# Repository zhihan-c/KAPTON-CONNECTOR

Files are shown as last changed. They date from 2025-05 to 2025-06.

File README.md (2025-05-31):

## Kapton Heater System for Oxidizer Tank Pressure Regulation

This system uses a 24V, 14.6A Kapton trace heater to regulate the pressure inside a nitrous oxide oxidizer tank, particularly in colder environments where vapor pressure drops below optimal levels. The heater is PWM-controlled via a high-current N-channel MOSFET, allowing for precise thermal regulation.

Designed by Brandon Moncriefe and Aslan Lauzon for QRET

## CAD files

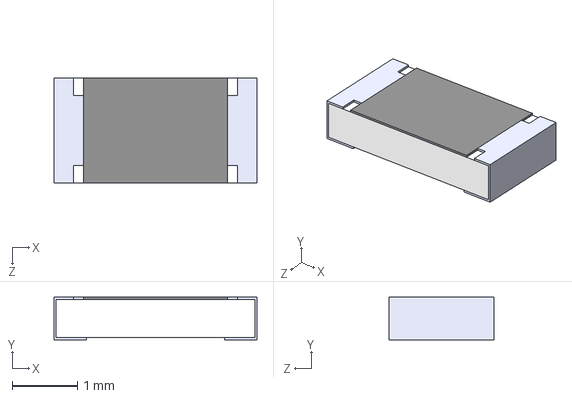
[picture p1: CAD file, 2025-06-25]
Component Footprints/CRCW120627R0FKEAHP/CRCW120627R0FKEAHP.step
3.10 x 0.65 x 1.60 mm

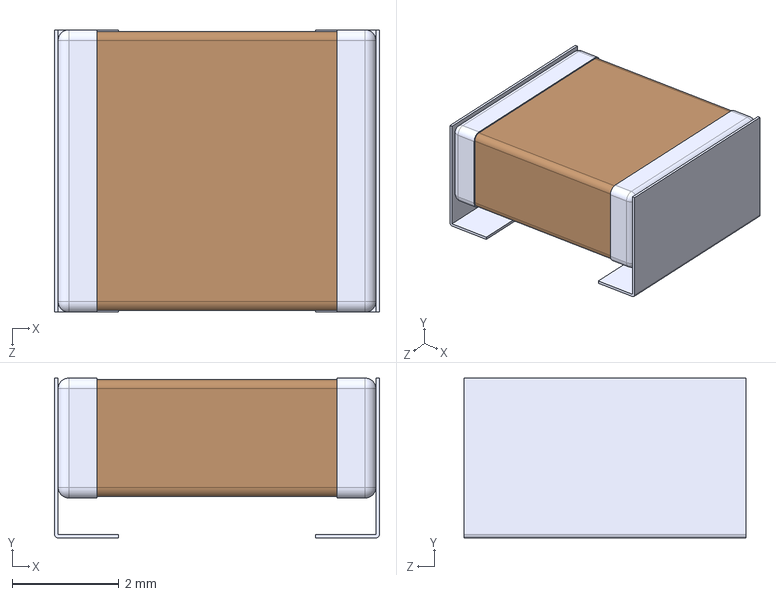
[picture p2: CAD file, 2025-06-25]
Component Footprints/KCM55LR71J475KH01K/KCM55LR71J475KH01K.step
6.10 x 3.00 x 5.30 mm

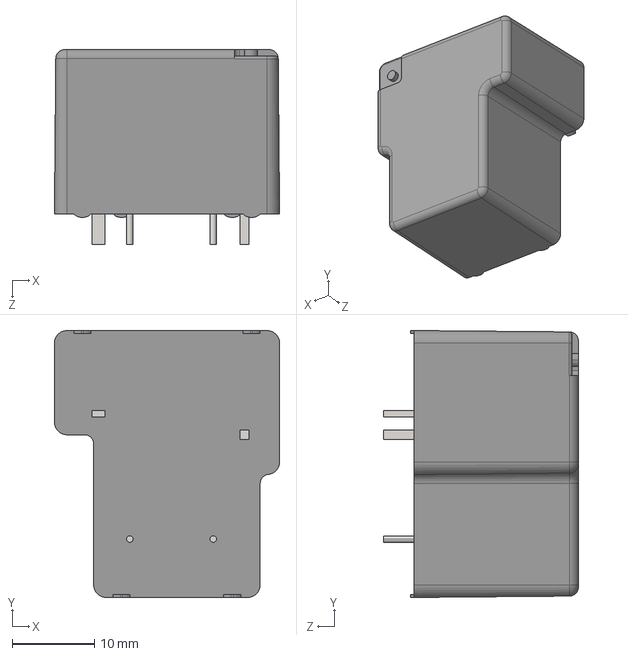
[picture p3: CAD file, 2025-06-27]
Component Footprints/LIB_T9AS1D12-5/T9AS1D12-5/3D/T9AS1D12-5.stp
27.4 x 32.5 x 23.7 mm

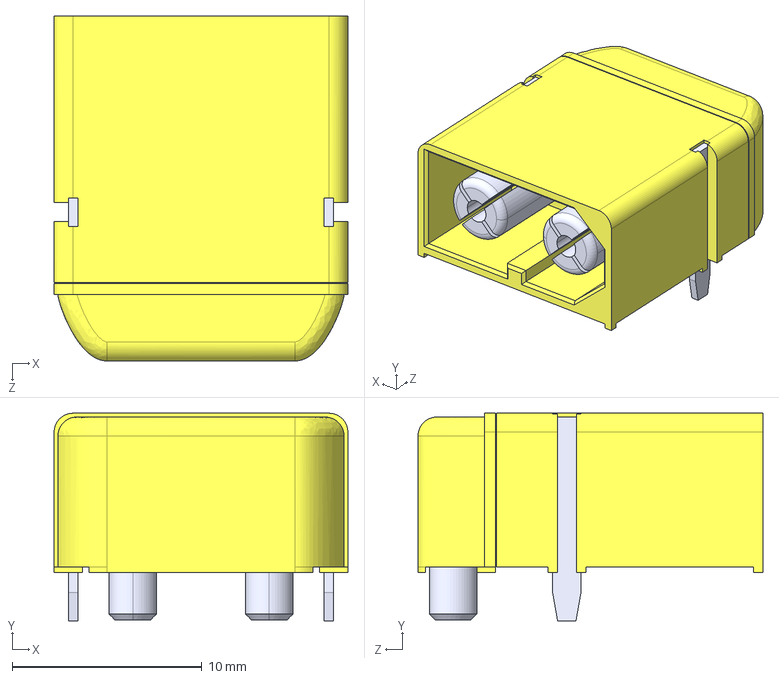
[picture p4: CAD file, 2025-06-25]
Component Footprints/XT60PW-M/XT60PW-M.step
15.5 x 11.0 x 18.2 mm

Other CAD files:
Component Footprints/LIB_T9AS1D12-5/T9AS1D12-5/Allegro/t9as1d125.psm
Component Footprints/LIB_T9AS1D12-5/T9AS1D12-5/DEHDL/t9as1d12_5/chips/chips.prt
Component Footprints/LIB_V20DM100C-M3_I/V20DM100C-M3_I/Allegro/v40dl45bpm3i.psm
Component Footprints/LIB_V20DM100C-M3_I/V20DM100C-M3_I/DEHDL/v20dm100c_m3_i/chips/chips.prt

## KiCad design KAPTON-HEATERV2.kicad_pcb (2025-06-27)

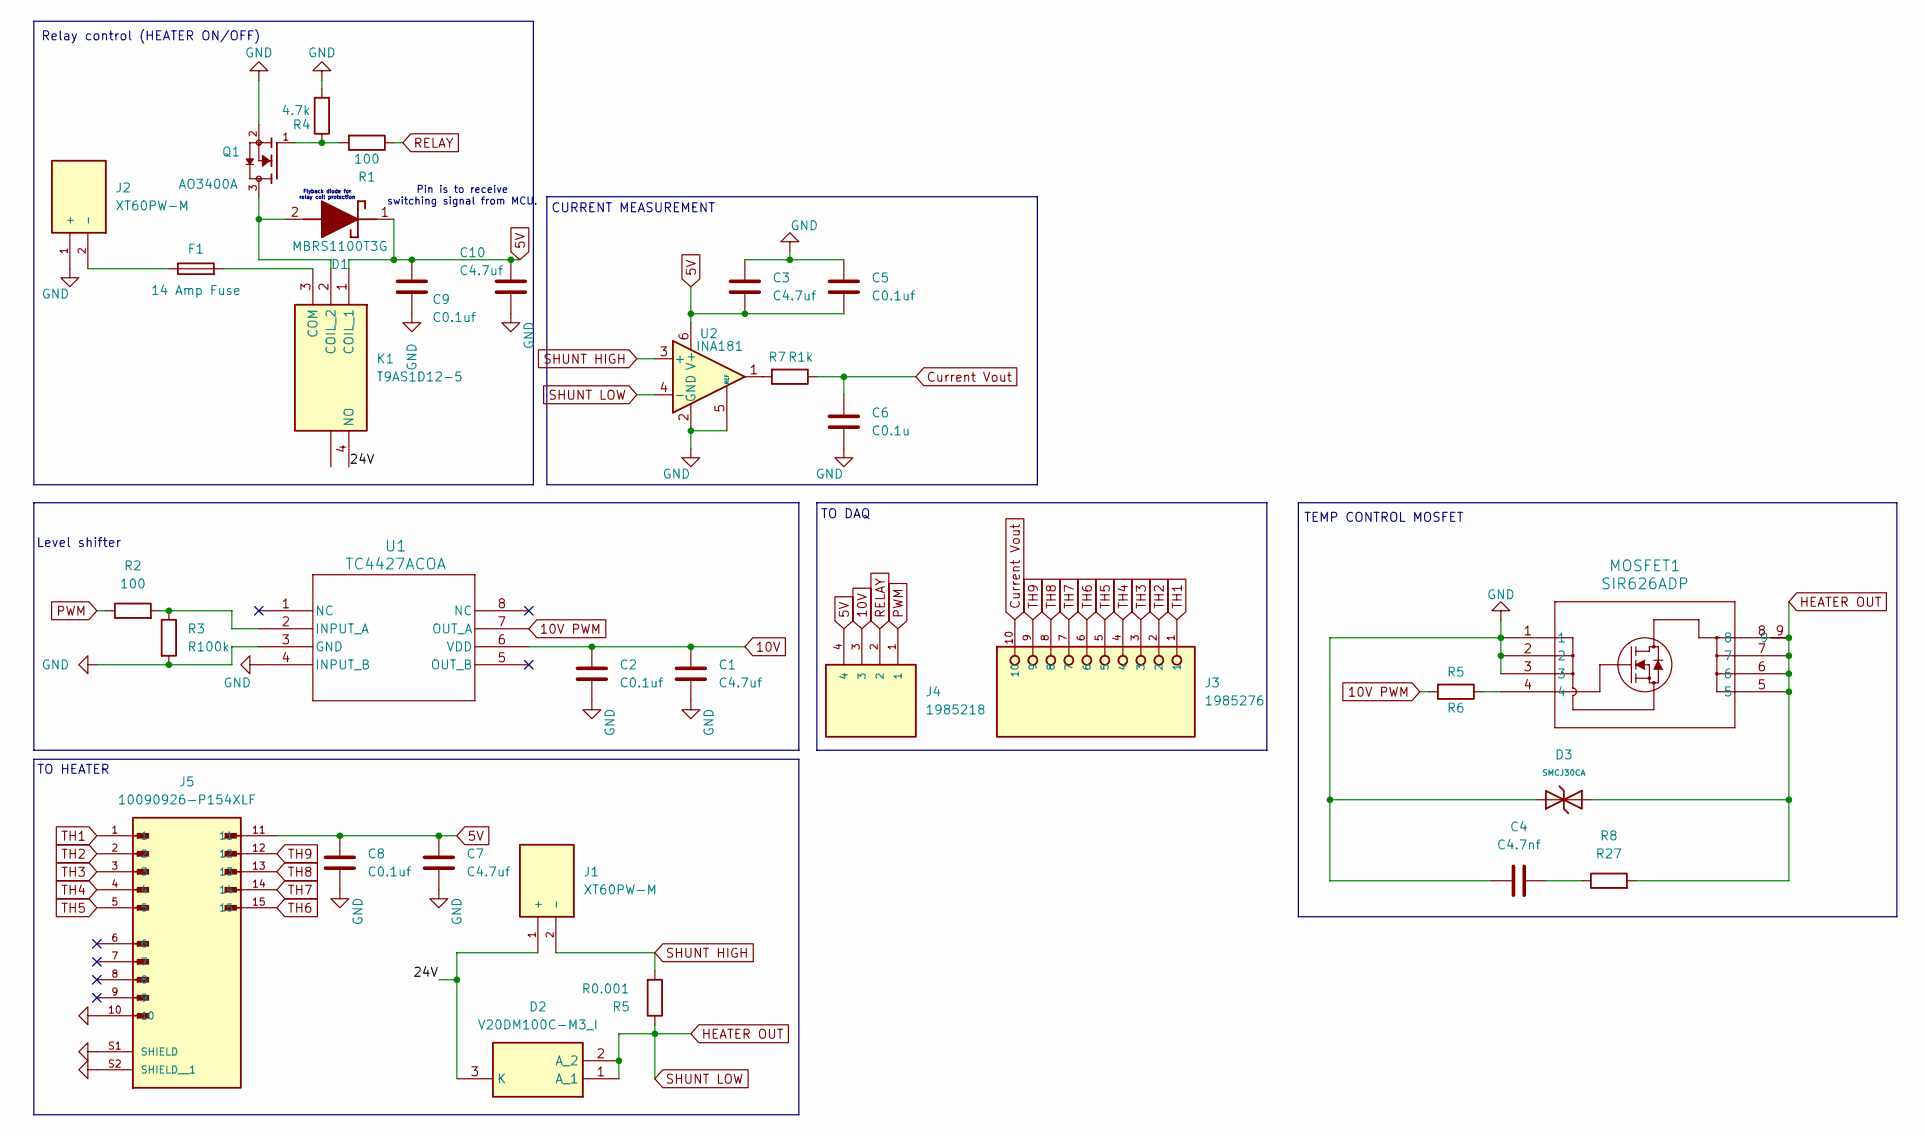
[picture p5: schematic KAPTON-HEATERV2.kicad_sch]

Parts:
C1, C3, C7, C10: C4.7uf; C_0805_2012Metric
C2, C5, C8, C9: C0.1uf; C_0805_2012Metric
C4: C4.7nf; CAPC6153X300N
C6: C0.1u; C_0805_2012Metric
D1: MBRS1100T3G; DIOM5436X247N; Mouser Part Number 863-MBRS1100T3G
D2: V20DM100C-M3_I; V40DL45BPM3I; Mouser Part Number 78-V20DM100C-M3/I
D3: SMCJ30CA; D_SMC; Part SMCJ30CA; LCSC C19077607
F1: 14 Amp Fuse; FUSRR508W60L835T400H810
J1, J2: XT60PW-M; AMASS_XT60PW-M; PARTREV V1.2
J3: 1985276; PHOENIX_1985276
J4: 1985218; TE_1985218; PARTREV 29.03.2021
J5: 10090926-P154XLF; AMPHENOL_10090926-P154XLF; PARTREV H
K1: T9AS1D12-5; T9AS1D125; Manufacturer_Part_Number T9AS1D12-5; Mouser Part Number 655-T9AS1D12-5
MOSFET1: SIR626ADP; POWERPAK_SO-8_SINGLE_VIS
Q1: AO3400A; SOT95P280X125-3N; PARTREV L
R1, R2: 100; R_0805_2012Metric
R3: R100k; R_0805_2012Metric
R4: 4.7k; R_0805_2012Metric
R5: R0.001; RESC6432X90N
R6: R5; R_0805_2012Metric
R7: R1k; R_0805_2012Metric
R8: R27; R_1206_3216Metric
U1: TC4427ACOA; SOIC8-N_MC_MCH
U2: INA181; SOT-23-6

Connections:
5V: C3.2, C5.2, C7.1, C8.1, C9.1, C10.1, D1.1 (K), J4.4, J5.11, K1.1 (COIL_1), U2.6 (V+)
10V: C1.1, C2.1, J4.3, U1.6 (VDD)
10V PWM: R6.2, U1.7 (OUT_A)
/24V: D2.3 (K), J1.1 (+), K1.4 (NO)
Current Vout: C6.1, J3.10, R7.1
GND: C1.2, C2.2, C3.1, C4.2, C5.1, C6.2, C7.2, C8.2, C9.2, C10.2, D3.2, J1.S1, J1.S2, J2.1 (+), J2.S1, J2.S2, J5.10, J5.S1 (SHIELD), J5.S2 (SHIELD__1), MOSFET1.1, MOSFET1.2, MOSFET1.3, Q1.2, R3.2, R4.2, U1.3 (GND), U1.4 (INPUT_B), U2.2 (GND), U2.5 (REF)
HEATER OUT: D2.1 (A_1), D2.2 (A_2), D3.1, MOSFET1.5, MOSFET1.6, MOSFET1.7, MOSFET1.8, MOSFET1.9, R5.1, R8.2, U2.4 (-)
unnamed: C4.1, R8.1
unnamed: D1.2 (A), K1.2 (COIL_2), Q1.3
unnamed: F1.1, J2.2 (-)
unnamed: F1.2, K1.3 (COM)
unnamed: MOSFET1.4, R6.1
unnamed: Q1.1, R1.2, R4.1
unnamed: R7.2, U2.1
unnamed: R2.2, R3.1, U1.2 (INPUT_A)
PWM: J4.1, R2.1
RELAY: J4.2, R1.1
SHUNT HIGH: J1.2 (-), R5.2, U2.3 (+)
TH1: J3.1, J5.1
TH2: J3.2, J5.2
TH3: J3.3, J5.3
TH4: J3.4, J5.4
TH5: J3.5, J5.5
TH6: J3.6, J5.15
TH7: J3.7, J5.14
TH8: J3.8, J5.13
TH9: J3.9, J5.12

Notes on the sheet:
TO HEATER
Relay control (HEATER ON/OFF)
TO DAQ
Flyback diode for relay coil protection
CURRENT MEASUREMENT
Level shifter
TEMP CONTROL MOSFET
Pin is to receive switching signal from MCU.

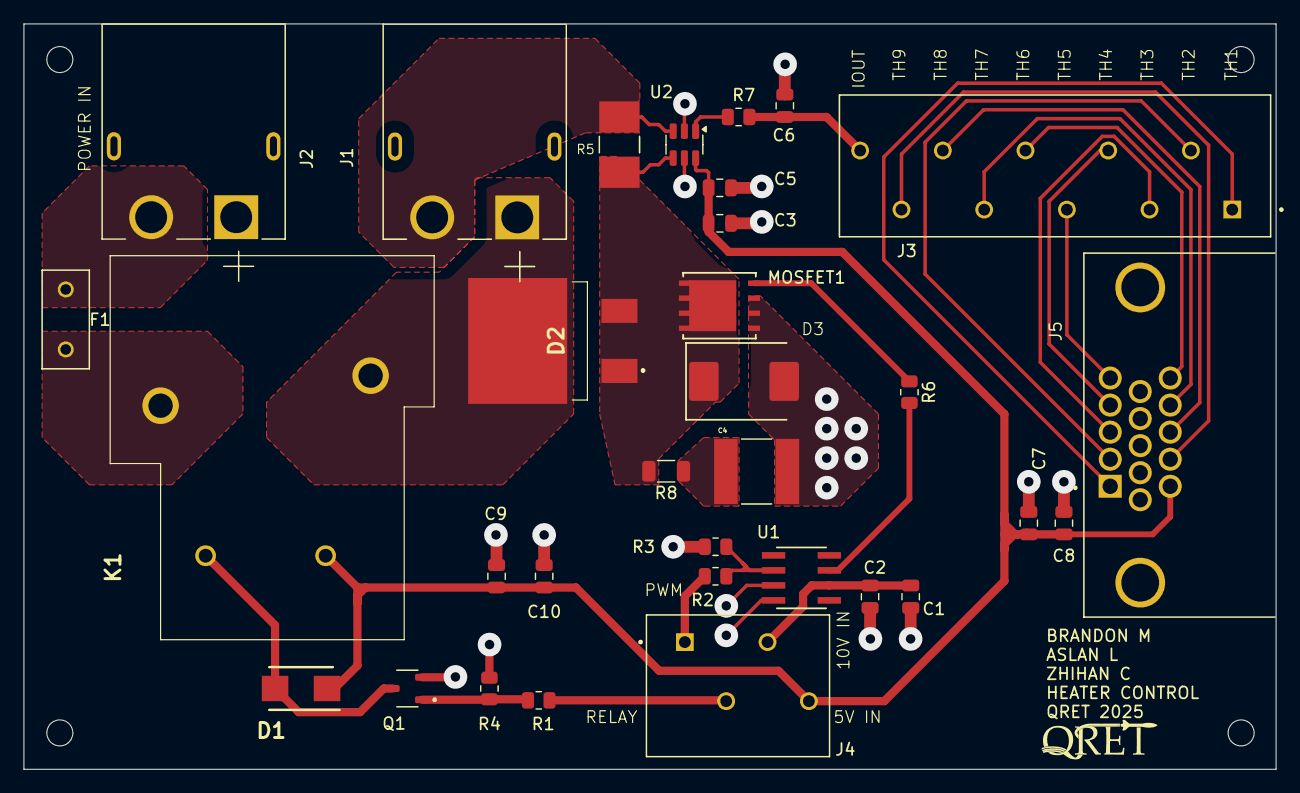
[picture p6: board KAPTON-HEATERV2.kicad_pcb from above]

Board: 2 copper layers, 106.0 x 63.1 mm, 32 parts (0 on the bottom side), 27 nets.

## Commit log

2025-06-01 added mounting holes
    [KAPTON-HEATERV2.kicad_pcb]
2025-06-04 forgot to save sch
    [KAPTON-HEATERV2.kicad_sch]
2025-06-04 added resistors to pcb
    [KAPTON-HEATERV2.kicad_pcb, KAPTON-HEATERV2.kicad_sch]
2025-06-05 fixed a trace
    [KAPTON-HEATERV2.kicad_pcb, KAPTON-HEATERV2.kicad_sch]
2025-06-05 fixed the mosfet
    [KAPTON-HEATERV2.kicad_pcb, KAPTON-HEATERV2.kicad_sch]
2025-06-17 added shunt resistor, fixed caps
    [KAPTON-HEATERV2.kicad_sch]
2025-06-17 edited sch, added footprints
    [KAPTON-HEATERV2.kicad_pcb, KAPTON-HEATERV2.kicad_sch]
2025-06-18 added current sensing
2025-06-18 working on pcb
    [KAPTON-HEATERV2.kicad_pcb, KAPTON-HEATERV2.kicad_sch]
2025-06-18 need to finish netclasses
    [KAPTON-HEATERV2.kicad_sch]
2025-06-21 iteration 1.2
    [KAPTON-HEATERV2.kicad_pcb, KAPTON-HEATERV2.kicad_sch]
2025-06-21 trace fix
    [KAPTON-HEATERV2.kicad_pcb]
2025-06-21 fixed DRC issues and made some traces pretty
    [KAPTON-HEATERV2.kicad_pcb]
2025-06-23 copper pour both sides
    [KAPTON-HEATERV2.kicad_pcb]
2025-06-25 June 26 New Traces
    [CRCW120627R0FKEAHP.step, EDI2CAP.CFG, KAPTON-HEATERV2.kicad_pcb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]
2025-06-26 Grounded Shield Connectors J1 J2
    [KAPTON-HEATERV2.kicad_pcb]
2025-06-27 New Relay Footprint
    [EDI2CAP.CFG, KAPTON-HEATERV2.kicad_pcb, KAPTON-HEATERV2.kicad_sch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]
2025-06-27 Rounded to Nearest mm
    [KAPTON-HEATERV2.kicad_pcb]
2025-06-27 Trace Edit and Gerbers
    [KAPTON-HEATERV2-B_Cu.gbl, KAPTON-HEATERV2-B_Mask.gbs, KAPTON-HEATERV2-B_Paste.gbp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]
2025-06-27 Updated Gerbers
    [KAPTON-HEATERV2-B_Cu.gbl, KAPTON-HEATERV2-B_Mask.gbs, KAPTON-HEATERV2-B_Paste.gbp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]
